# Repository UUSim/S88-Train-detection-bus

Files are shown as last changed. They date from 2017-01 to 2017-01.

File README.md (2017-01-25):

# S88-Train-detection-bus
PCB designs for an S88 bus for detecting model trains on a track. The Marklin S88 bus is based on a shift register. More information on the Marklin S88 bus can be found here:
* [S88-N - s88 over RJ45](http://www.s88-n.eu/index-en.html) (English)
* [Digital Bahn.de](https://www.digital-bahn.de/info_tech/s88.htm) (Deutsch)
* [Marklin S88 Link](http://www.maerklin.de/en/products/details/article/60883/) ([PDF manual](https://static.maerklin.de/damcontent/d1/65/d1652564aaf7fea4ec6f6f887203d2681464362779.pdf)) (English/Deutsch)
* [Avontuur in miniatuur - Terugmelding](http://www.floodland.nl/aim/info_terugmelding_1.htm) (Nederlands)

This design uses master and slave boards, connected to a single bus controller (e.g. a Marklin CS or an Arduino). Both boards are suitable for DIY-etching (master: uv-lighting, slave: toner-tranfer). The number of drilling-holes is kept to a minimum. **Note: there is no hysteresis on the inputs. This must be implemented in the controller software.**
## Master board
The master board uses 3 74hc165 ICs, resulting in 24 inputs. The master boards can be chained together. Each connector on the master board serves a group of 3 inputs, which are connected via a slave board. All inputs are fitted with pullups. The train wheels connect the inputs to ground when entering a track section.

[See the InputModule for the design files of the master board](InputModule/README.md)

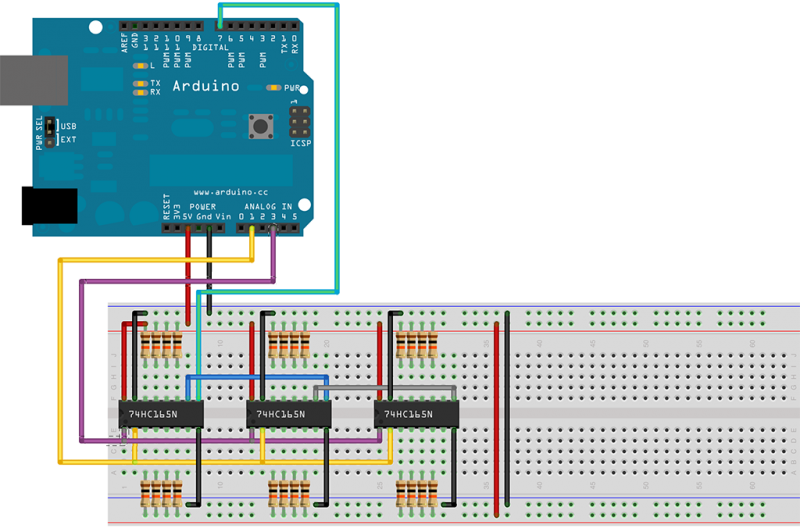
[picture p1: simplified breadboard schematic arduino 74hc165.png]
Breadboard schematic of the master board


## Slave board
A small slave board can be mounted close to the tracks, and connects up to 3 track segments. The board features a led for diagnostic purposes.  
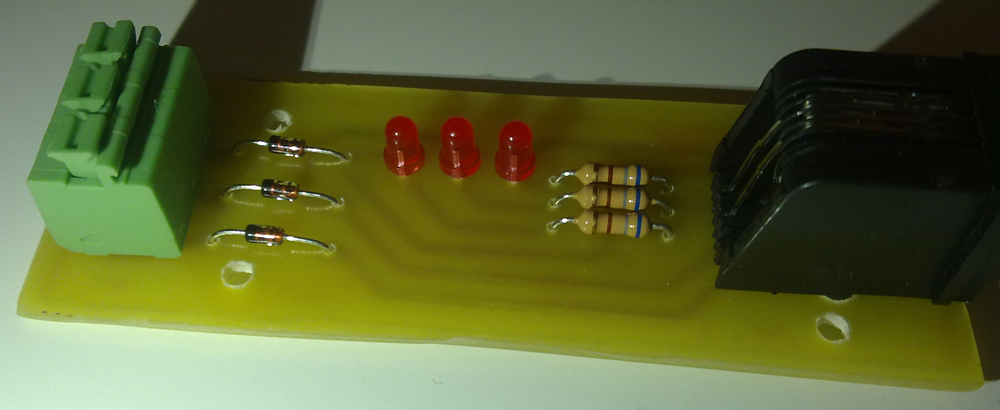
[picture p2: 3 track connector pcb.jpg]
Picture of the slave board

## Video of result
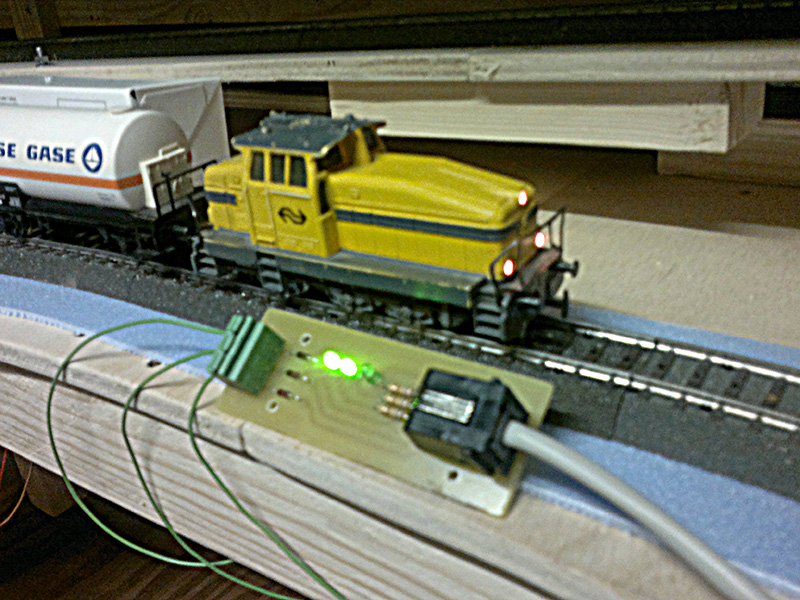
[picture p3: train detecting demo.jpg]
A train is detected on the track
[!](https://www.youtube.com/watch?v=ed31EqeW7o0)

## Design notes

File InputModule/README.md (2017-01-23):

# InputModule
PCB designs of the Input module of the S88 train detection bus. This is the master board. It uses 3 74hc165 ICs, resulting in 24 inputs. The master boards can be chained together via RJ45 connectors. Each RJ11 connector on the master board serves a group of 3 inputs, which are connected via a slave board.
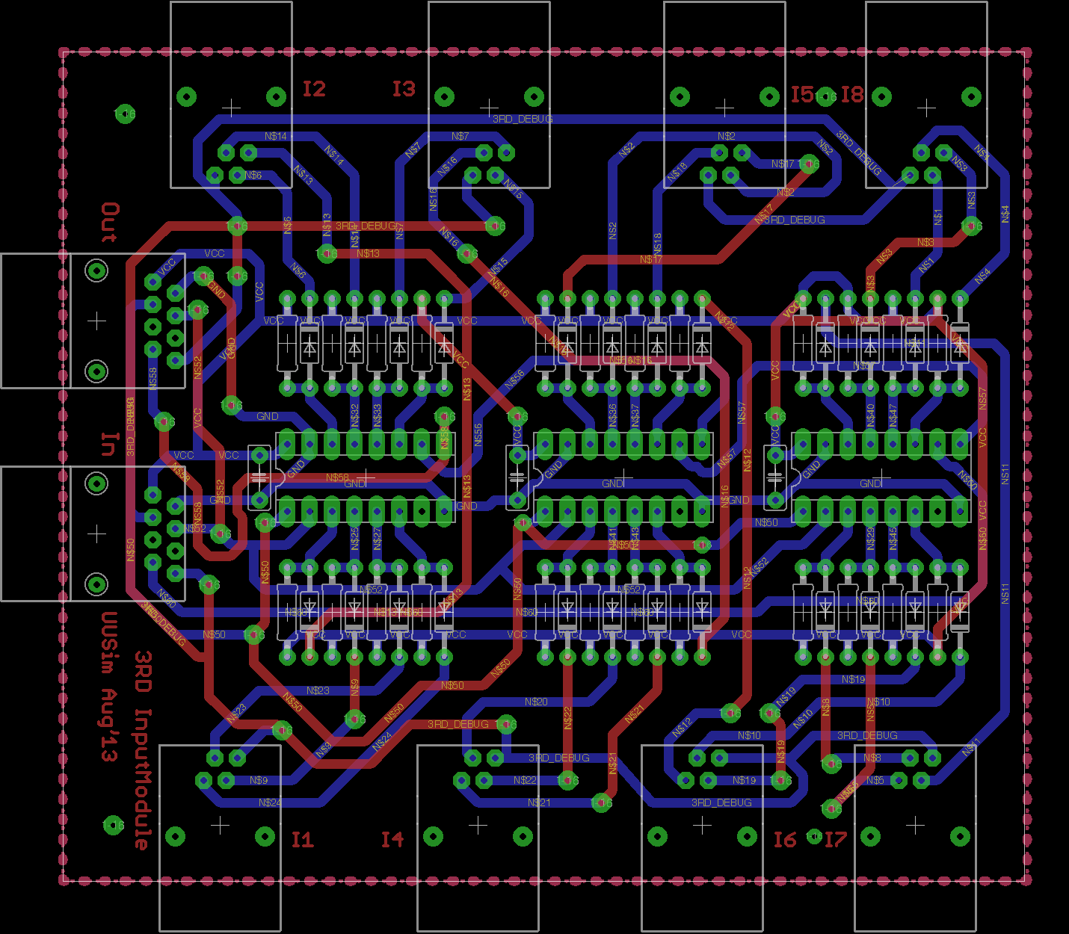
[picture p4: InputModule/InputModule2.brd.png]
Board layout of the master board


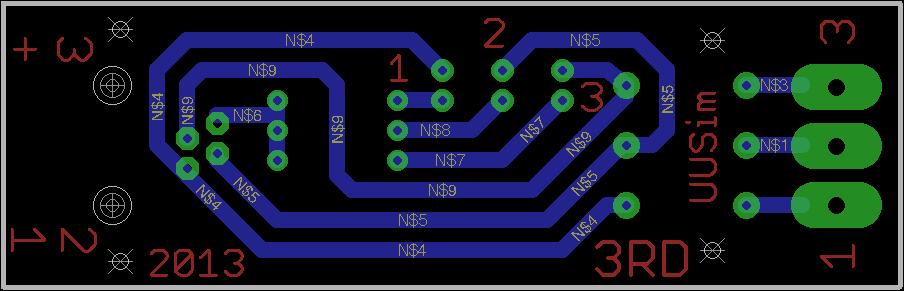
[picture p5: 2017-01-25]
RailSlave/RailSlave.brd.png

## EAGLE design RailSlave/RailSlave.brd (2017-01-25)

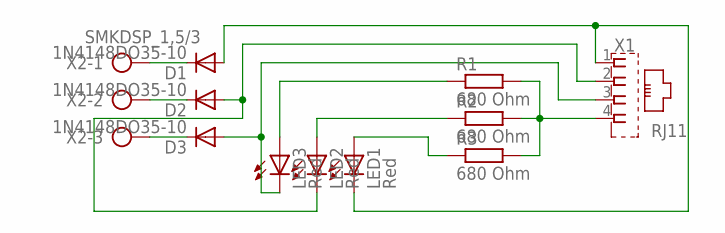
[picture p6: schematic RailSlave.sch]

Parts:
D1, D2, D3: 1N4148DO35-10; DO35-10
LED1, LED2, LED3: Red; LED3MM
R1, R2, R3: 680 Ohm; 0207/10
X1: RJ11; RJ116PC4
X2: SMKDSP_1,5/3

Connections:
unnamed: D2.C, X2.2
unnamed: D1.C, X2.1
unnamed: D3.C, X2.3
unnamed: D1.A, LED1.K (C), X1.1
unnamed: D2.A, LED2.K (C), X1.2
unnamed: R1.2, R2.2, R3.2, X1.4
unnamed: LED3.A, R1.1
unnamed: LED2.A, R2.1
unnamed: D3.A, LED3.K (C), X1.3
unnamed: LED1.A, R3.1

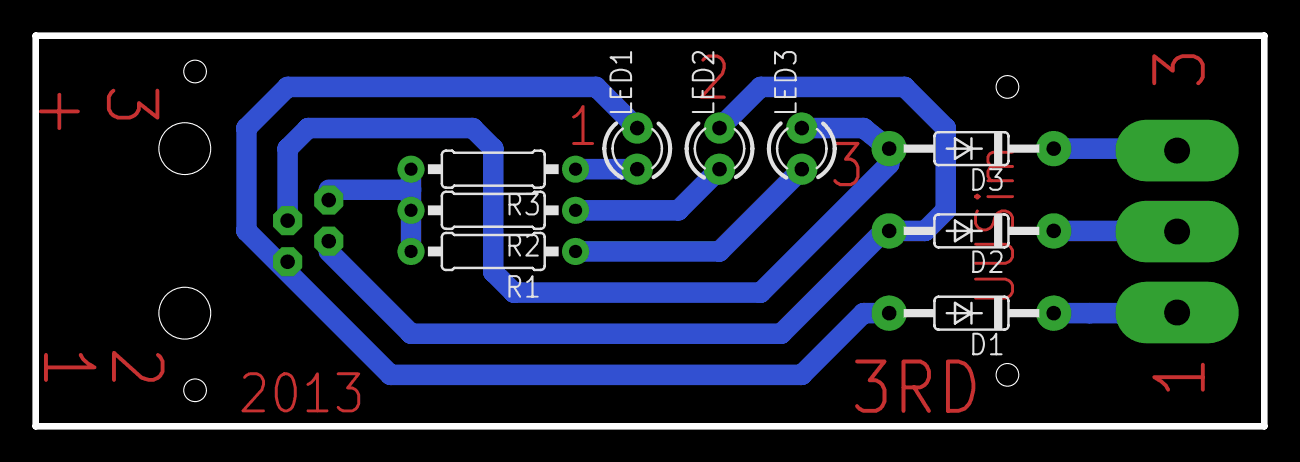
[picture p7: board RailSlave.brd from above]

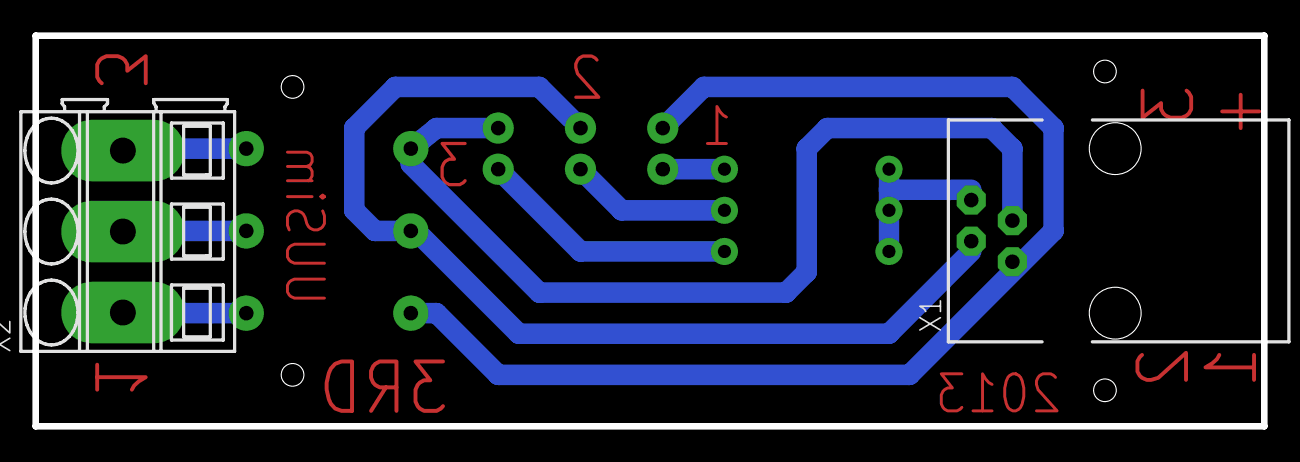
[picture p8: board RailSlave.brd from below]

Board: 2 copper layers, 75.9 x 24.1 mm, 11 parts (2 on the bottom side), 10 nets.

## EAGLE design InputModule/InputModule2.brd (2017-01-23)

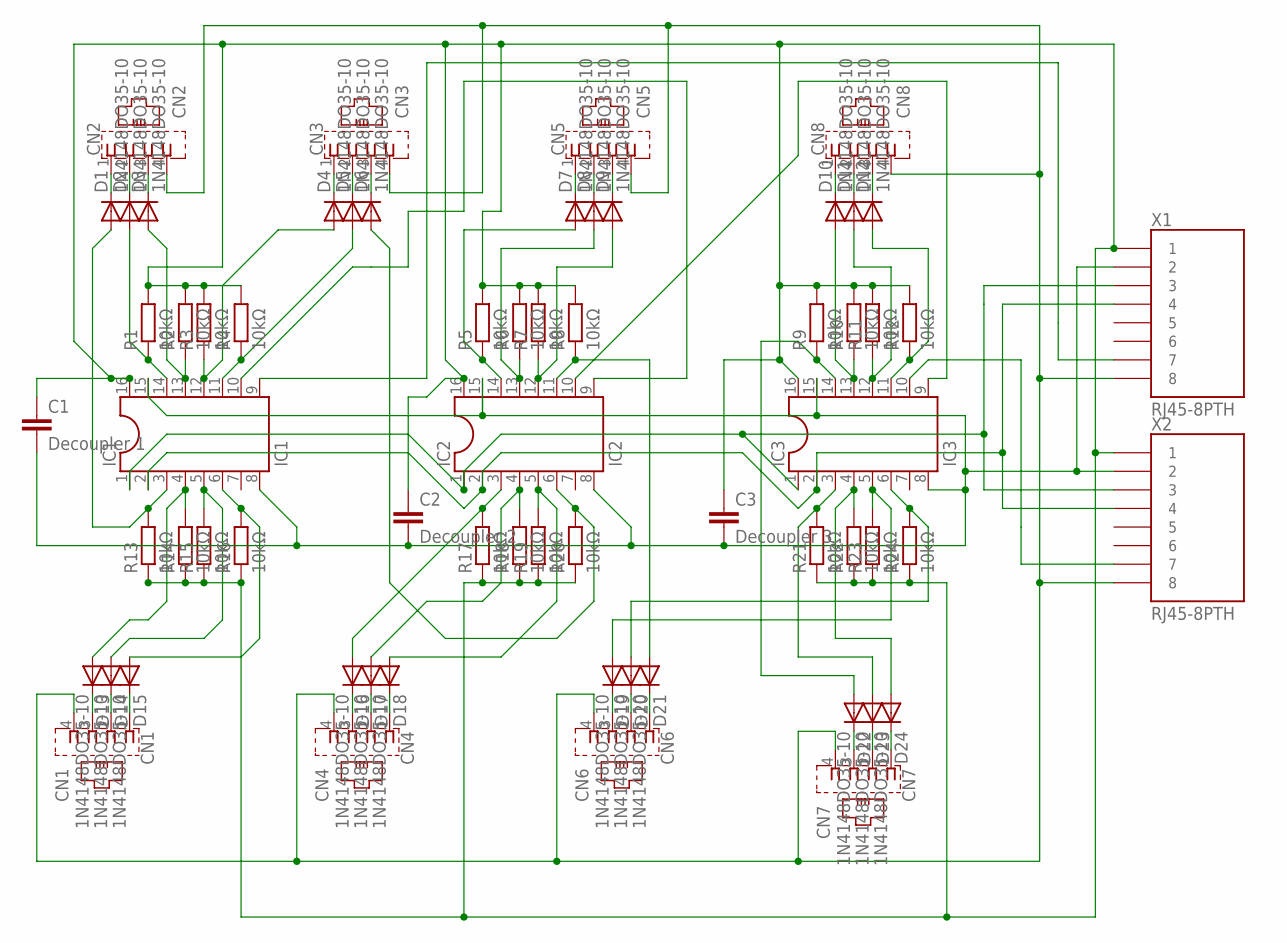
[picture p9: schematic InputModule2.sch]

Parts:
C1: Decoupler 1; C5B2.5
C2: Decoupler 2; C5B2.5
C3: Decoupler 3; C5B2.5
CN1: CN1; RJ116PC4
CN2: CN2; RJ116PC4
CN3: CN3; RJ116PC4
CN4: CN4; RJ116PC4
CN5: CN5; RJ116PC4
CN6: CN6; RJ116PC4
CN7: CN7; RJ116PC4
CN8: CN8; RJ116PC4
D1, D2, D3, D4, D5, D6, D7, D8, D9, D10, D11, D12, D13, D14, D15, D16, D17, D18, D19, D20, D21, D22, D23, D24: 1N4148DO35-10; DO35-10
IC1: IC1; SOCKET-16
IC2: IC2; SOCKET-16
IC3: IC3; SOCKET-16
R1, R2, R3, R4, R5, R6, R7, R8, R9, R10, R11, R12, R13, R14, R15, R16, R17, R18, R19, R20, R21, R22, R23, R24: 10kΩ; 0207/10
X1, X2: RJ45-8PTH; RJ45-8

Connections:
3RD_DEBUG: CN1.4, CN2.4, CN3.4, CN4.4, CN5.4, CN6.4, CN7.4, CN8.4, X1.8, X2.8
GND: C1.2, C2.2, C3.2, IC1.8, IC1.15, IC2.8, IC2.15, IC3.8, IC3.15, X1.2, X2.2
unnamed: CN8.2, D11.C
unnamed: CN5.2, D8.C
unnamed: CN8.1, D10.C
unnamed: CN8.3, D12.C
unnamed: CN7.1, D24.C
unnamed: CN2.2, D2.C
unnamed: CN3.1, D4.C
unnamed: CN7.2, D23.C
unnamed: CN1.3, D13.C
unnamed: CN6.2, D20.C
unnamed: CN7.3, D22.C
unnamed: CN6.1, D21.C
unnamed: CN2.1, D1.C
unnamed: CN2.3, D3.C
unnamed: CN3.2, D5.C
unnamed: CN3.3, D6.C
unnamed: CN5.1, D7.C
unnamed: CN5.3, D9.C
unnamed: CN6.3, D19.C
unnamed: CN4.2, D17.C
unnamed: CN4.1, D18.C
unnamed: CN4.3, D16.C
unnamed: CN1.2, D14.C
unnamed: CN1.1, D15.C
unnamed: D13.A, IC1.4, R14.2
unnamed: D1.A, IC1.3, R13.2
unnamed: D14.A, IC1.5, R15.2
unnamed: D12.A, IC3.11, R12.1
unnamed: D24.A, IC3.4, R22.2
unnamed: D20.A, IC3.6, R24.2
unnamed: D2.A, IC1.14, R1.1
unnamed: D3.A, IC1.13, R2.1
unnamed: D4.A, IC1.12, R3.1
unnamed: D5.A, IC1.11, R4.1
unnamed: D7.A, IC2.14, R5.1
unnamed: D8.A, IC2.13, R6.1
unnamed: D9.A, IC2.12, R7.1
unnamed: D21.A, IC2.11, R8.1
unnamed: D15.A, IC1.6, R16.2
unnamed: D10.A, IC3.13, R10.1
unnamed: D17.A, IC2.4, R18.2
unnamed: D16.A, IC2.3, R17.2
unnamed: D18.A, IC2.5, R19.2
unnamed: D6.A, IC2.6, R20.2
unnamed: D19.A, IC3.5, R23.2
unnamed: D23.A, IC3.3, R21.2
unnamed: D11.A, IC3.12, R11.1
unnamed: D22.A, IC3.14, R9.1
unnamed: IC1.1, IC2.1, IC3.1, X1.3, X2.3
unnamed: IC1.2, IC2.2, IC3.2, X1.4, X2.4
unnamed: IC1.10, IC2.9
unnamed: IC2.10, IC3.9
unnamed: IC1.9, X1.7
unnamed: IC3.10, X2.7
VCC: C1.1, C2.1, C3.1, IC1.16, IC2.16, IC3.16, R1.2, R2.2, R3.2, R4.2, R5.2, R6.2, R7.2, R8.2, R9.2, R10.2, R11.2, R12.2, R13.1, R14.1, R15.1, R16.1, R17.1, R18.1, R19.1, R20.1, R21.1, R22.1, R23.1, R24.1, X1.1, X2.1

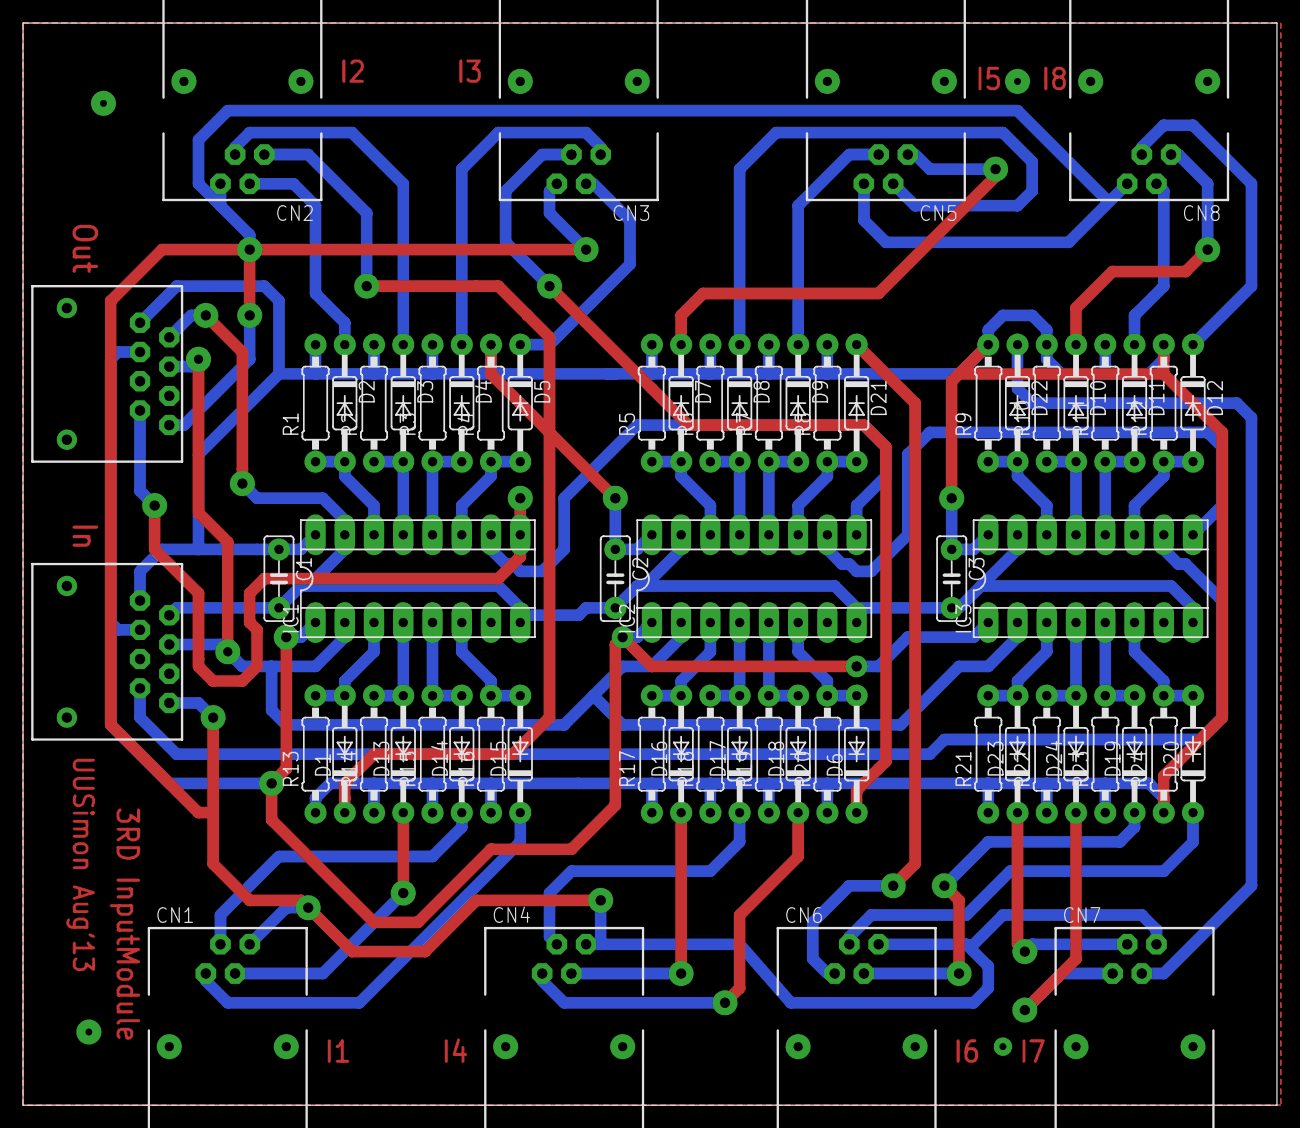
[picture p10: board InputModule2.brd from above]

Board: 2 copper layers, 108.9 x 94.0 mm, 64 parts (0 on the bottom side), 57 nets.

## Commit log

2017-01-20 Added pictures of result
    Also includes breadboard schematic of s88 bus with shift registers
2017-01-23 Added Eagle design files for the master board. Added readme with screenshot.
    [InputModule2.brd, InputModule2.sch]
2017-01-23 Linked master board design files in readme
2017-01-25 Updated readme with links to S88 bus specifications. Added design files of the slave board.
    [RailSlave.brd, RailSlave.sch]

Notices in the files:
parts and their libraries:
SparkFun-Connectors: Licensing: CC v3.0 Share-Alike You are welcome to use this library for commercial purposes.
